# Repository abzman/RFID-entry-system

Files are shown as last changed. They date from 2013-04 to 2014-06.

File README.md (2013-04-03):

RFID-entry-system
=================

RFID entry system for i3 Detroit based on the Open Access Control 3.0, ethernet shield v5, arduino mega 2560, and Static Controls Corporation 1080 displays (RS485)

For an up to date overview please visit http://i3detroit.com/wi/index.php?title=RFID_entry_system

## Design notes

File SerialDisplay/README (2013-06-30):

display test out of date, uses the 2-wire shift register system

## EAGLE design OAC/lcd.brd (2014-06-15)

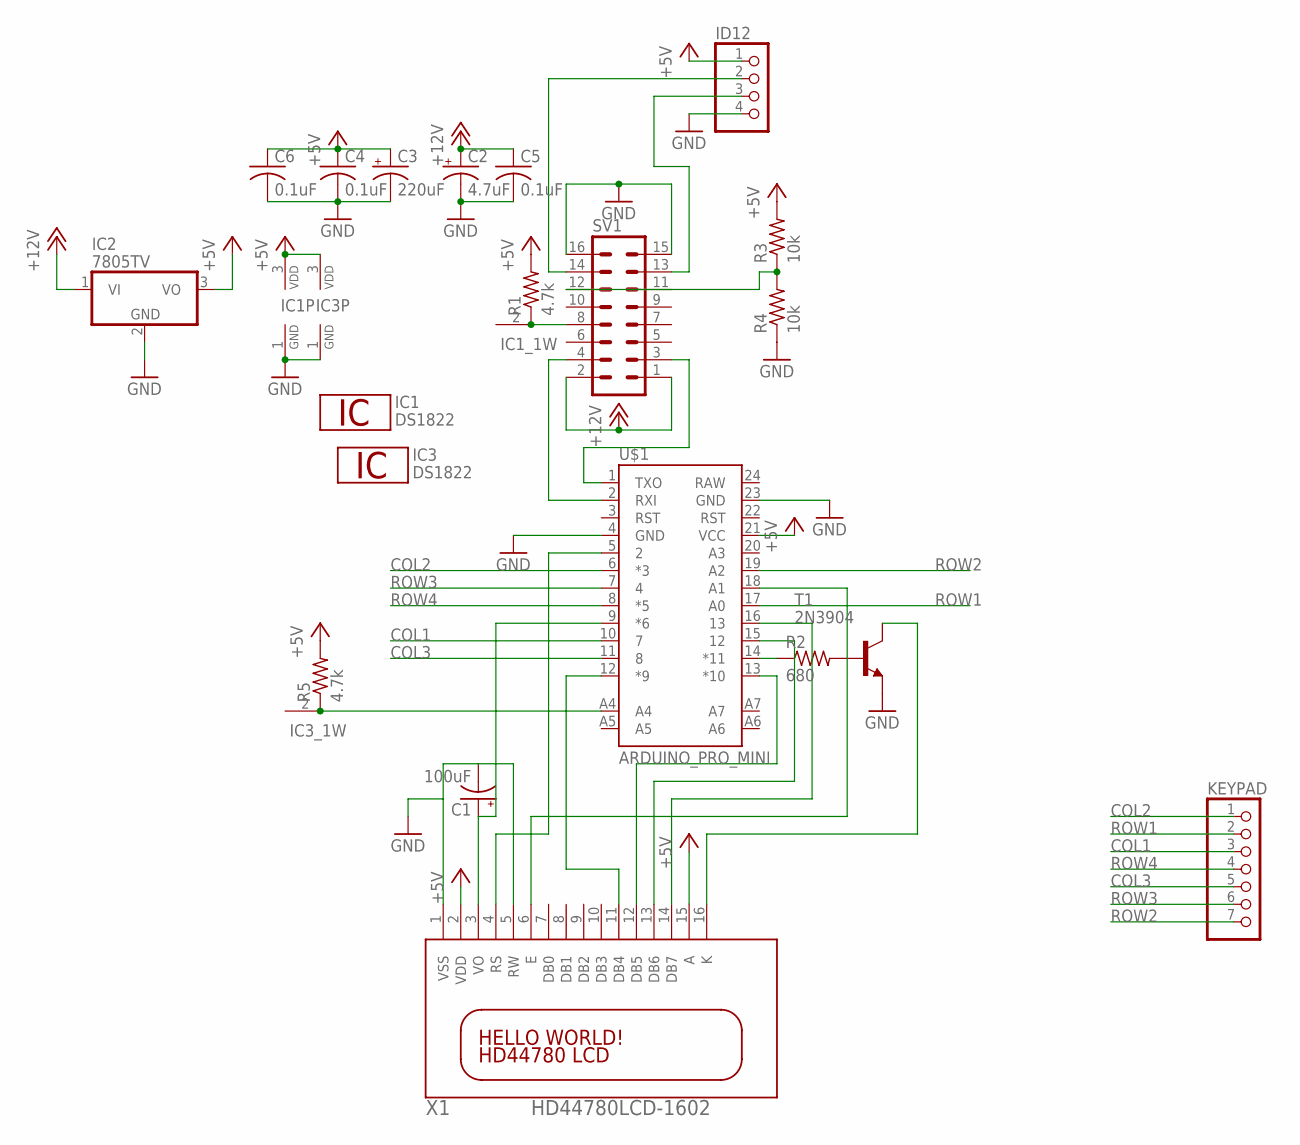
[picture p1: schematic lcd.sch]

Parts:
C1: 100uF; E2,5-7
C2: 4.7uF; E2,5-6
C3: 220uF; E5-8,5
C4, C5, C6: 0.1uF; C025-025X050
IC1, IC3: DS1822; TO92-
IC2: 7805TV; TO220V
ID12: PINHD-1X4; 1X04
KEYPAD: PINHD-1X7; 1X07
R1, R5: 4.7k; 0207/5V
R2: 680; 0207/5V
R3, R4: 10k; 0204V
SV1: ML16
T1: 2N3904; TO92
U$1: ARDUINO_PRO_MINI
X1: HD44780LCD-1602; LCD1602

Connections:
+5V: C3.+, C4.1, C6.1, IC1.3 (VDD), IC2.3 (VO), IC3.3 (VDD), ID12.1, R1.2, R3.2, R5.2, U$1.21 (VCC), X1.2 (VDD), X1.15 (A)
+12V: C2.+, C5.1, IC2.1 (VI), SV1.1, SV1.2
COL1: KEYPAD.3, U$1.10 (7)
COL2: KEYPAD.1, U$1.6 (*3)
COL3: KEYPAD.5, U$1.11 (8)
GND: C1.-, C2.-, C3.-, C4.2, C5.2, C6.2, IC1.1 (GND), IC2.2 (GND), IC3.1 (GND), ID12.4, R4.1, SV1.15, SV1.16, T1.3 (E), U$1.4 (GND), U$1.23 (GND), X1.1 (VSS), X1.5 (RW)
unnamed: IC1.2 (1W), R1.1, SV1.8
unnamed: C1.+, U$1.9 (*6), X1.3 (VO)
unnamed: SV1.4, U$1.2 (RXI)
unnamed: R2.1, U$1.14 (*11)
unnamed: R2.2, T1.2 (B)
unnamed: SV1.3, U$1.1 (TXO)
unnamed: ID12.2, SV1.14
unnamed: ID12.3, SV1.13
unnamed: T1.1 (C), X1.16 (K)
unnamed: U$1.5 (2), X1.4 (RS)
unnamed: U$1.18 (A1), X1.6 (E)
unnamed: U$1.12 (*9), X1.11 (DB4)
unnamed: U$1.13 (*10), X1.12 (DB5)
unnamed: U$1.15 (12), X1.13 (DB6)
unnamed: U$1.16 (13), X1.14 (DB7)
unnamed: R3.1, R4.2, SV1.12
unnamed: IC3.2 (1W), R5.1, U$1.A4
ROW1: KEYPAD.2, U$1.17 (A0)
ROW2: KEYPAD.7, U$1.19 (A2)
ROW3: KEYPAD.6, U$1.7 (4)
ROW4: KEYPAD.4, U$1.8 (*5)

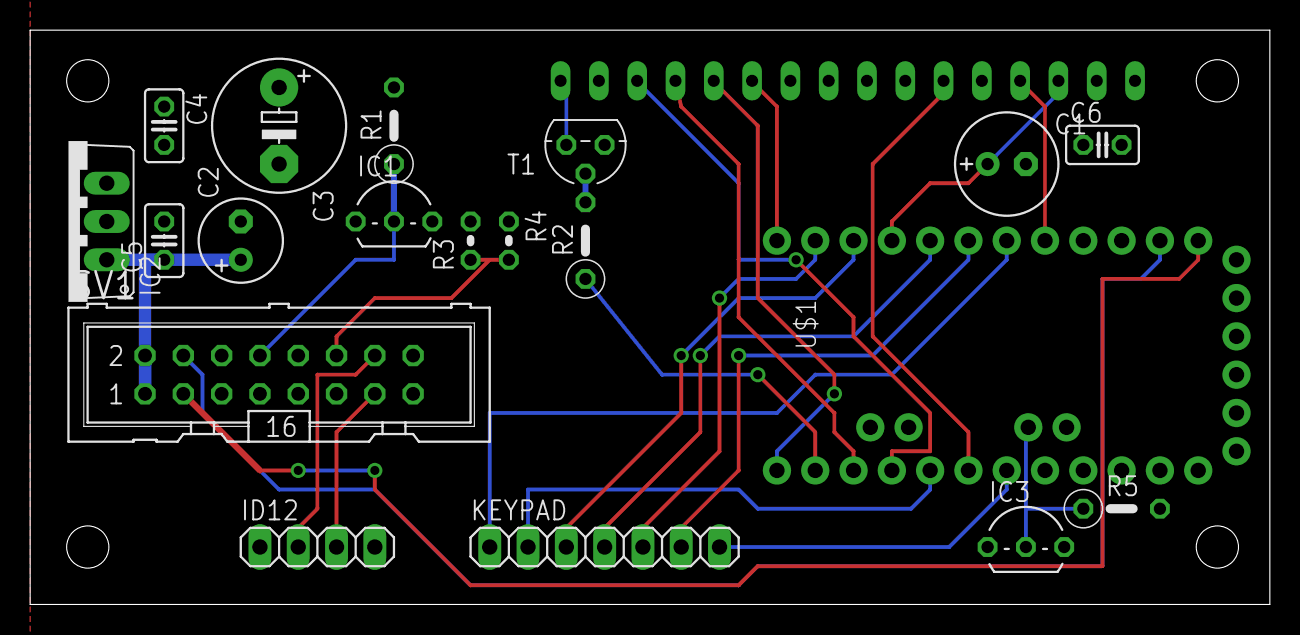
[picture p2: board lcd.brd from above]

Board: 2 copper layers, 82.2 x 38.1 mm, 20 parts (1 on the bottom side), 27 nets.

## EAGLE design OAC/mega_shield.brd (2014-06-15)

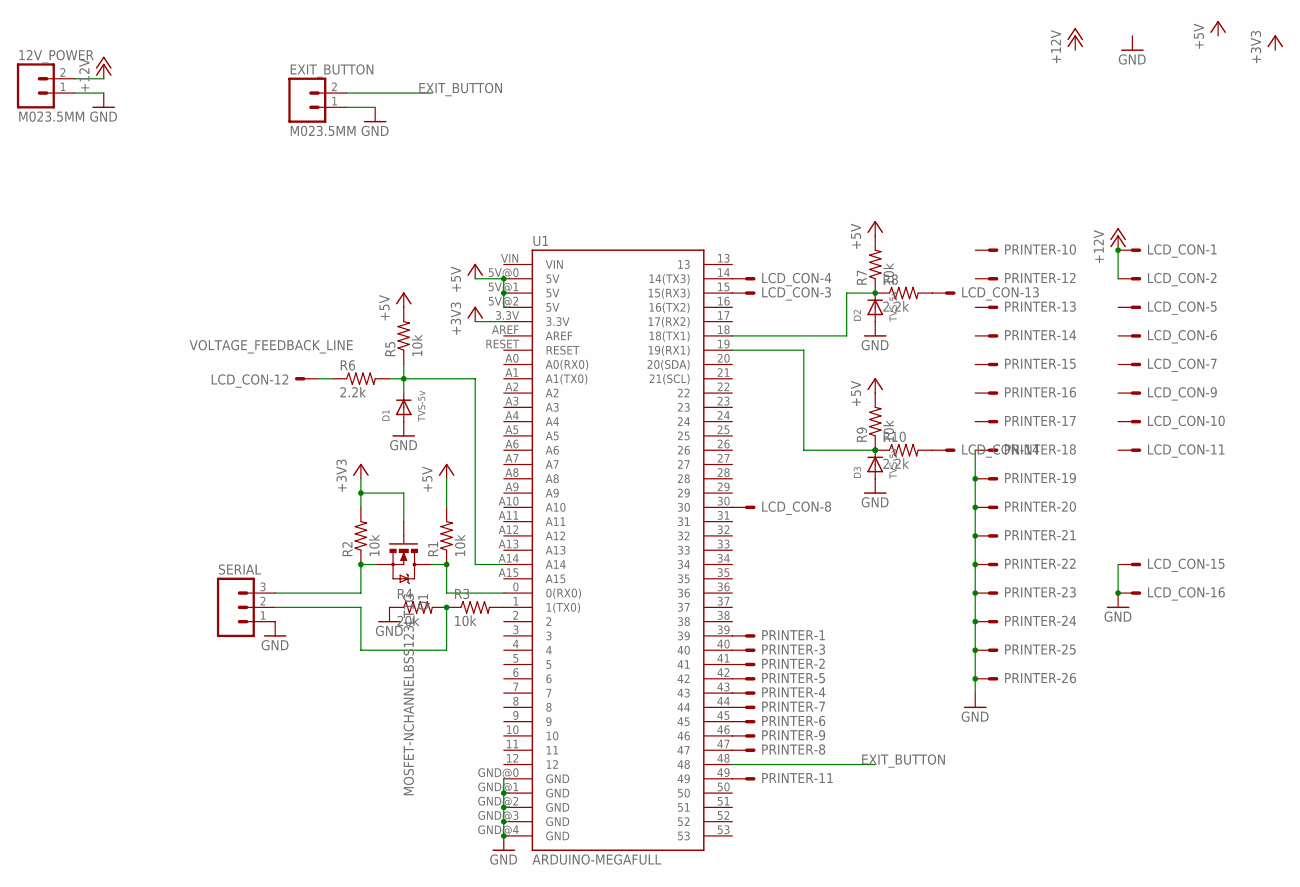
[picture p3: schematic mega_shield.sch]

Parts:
12V_POWER: M023.5MM; SCREWTERMINAL-3.5MM-2
D1, D2, D3: TVS-5v; SOD-123
EXIT_BUTTON: M023.5MM; SCREWTERMINAL-3.5MM-2
LCD_CON: ML16E; ML16
PRINTER: ML26E; ML26
Q1: MOSFET-NCHANNELBSS123LT1G; SOT23
R1, R2, R3, R5, R7, R9: 10k; R0603
R4: 20k; R0603
R6, R8, R10: 2.2k; R0603
SERIAL: M03SCREW; SCREWTERMINAL-3.5MM-3
U1: ARDUINO-MEGAFULL; ARDUINO_MEGA

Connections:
+3V3: Q1.1 (G), R2.2, U1.3.3V
+5V: R1.2, R5.2, R7.2, R9.2, U1.5V@0 (5V), U1.5V@1 (5V), U1.5V@2 (5V)
+12V: 12V_POWER.2, LCD_CON.1, LCD_CON.2
EXIT_BUTTON: EXIT_BUTTON.2, U1.48
GND: 12V_POWER.1, D1.A, D2.A, D3.A, EXIT_BUTTON.1, LCD_CON.15, LCD_CON.16, PRINTER.18, PRINTER.19, PRINTER.20, PRINTER.21, PRINTER.22, PRINTER.23, PRINTER.24, PRINTER.25, PRINTER.26, R4.1, SERIAL.1, U1.GND@0 (GND), U1.GND@1 (GND), U1.GND@2 (GND), U1.GND@3 (GND), U1.GND@4 (GND)
unnamed: LCD_CON.3, U1.15 (15(RX3))
unnamed: LCD_CON.4, U1.14 (14(TX3))
unnamed: PRINTER.1, U1.39
unnamed: PRINTER.11, U1.49
unnamed: PRINTER.2, U1.41
unnamed: PRINTER.3, U1.40
unnamed: PRINTER.4, U1.43
unnamed: PRINTER.5, U1.42
unnamed: PRINTER.6, U1.45
unnamed: PRINTER.7, U1.44
unnamed: PRINTER.8, U1.47
unnamed: PRINTER.9, U1.46
unnamed: LCD_CON.8, U1.30
unnamed: R3.2, U1.1 (1(TX0))
unnamed: R3.1, R4.2, SERIAL.2
unnamed: D1.C, R5.1, R6.2, U1.A14
unnamed: Q1.2 (S), R2.1, SERIAL.3
unnamed: Q1.3 (D), R1.1, U1.0 (0(RX0))
unnamed: D2.C, R7.1, R8.1, U1.18 (18(TX1))
unnamed: D3.C, R9.1, R10.1, U1.19 (19(RX1))
unnamed: LCD_CON.13, R8.2
unnamed: LCD_CON.14, R10.2
VOLTAGE_FEEDBACK_LINE: LCD_CON.12, R6.1

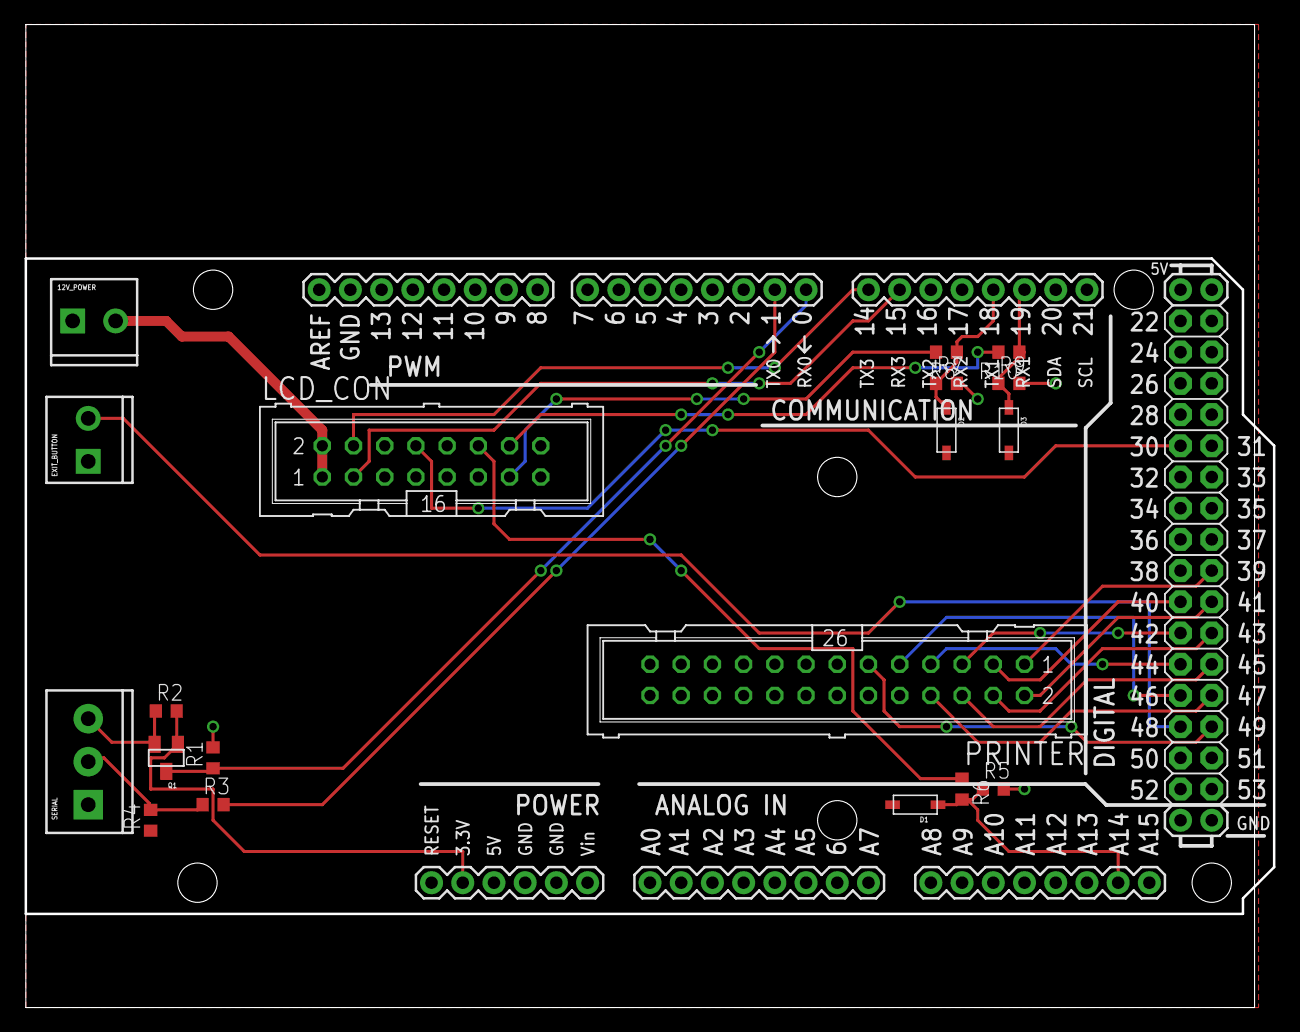
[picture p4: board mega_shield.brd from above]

Board: 2 copper layers, 101.6 x 80.0 mm, 20 parts (0 on the bottom side), 28 nets.

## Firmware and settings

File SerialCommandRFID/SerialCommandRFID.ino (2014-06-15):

// RFID project
// i3 Detroit
// Evan Allen
// January 2014

#define PRIV_ACCESS 0   //allowed to enter space
#define PRIV_ADDUSER 1  //allowed to add or remove users
#define PRIV_DOORBELL 2 //allowed to set doorbell mode
#define PRIV_DOORHOLD 3 //allowed to set door hold mode

#include <MD5.h>
#include <Arduino.h>
#include <String.h>


//library to allow it to take commands from serial
#include <SerialCommand2560.h>
SerialCommand2560 SCmd;   // The demo SerialCommand object


// Interface to DS1822 chip, record data to EEPROM
#include <OneWire.h>
OneWire ds(30);  // define the pin the interface is on */
float current_temperature;

//I2C stuff
#include <Wire.h>         // Needed for I2C Connection to the DS1307 date/time chip
#include <DS1307.h>       // DS1307 RTC Clock/Date/Time chip library
#include <E24C1024.h>     // Needed for the onboard EEPROM
uint8_t second, minute, hour, dayOfWeek, dayOfMonth, month, year;     // Global RTC clock variables. Can be set using DS1307.getDate function.
DS1307 ds1307;        // RTC Instance


//RFID reader stuff
#include <WIEGAND26.h>    // Wiegand 26 reader format library
byte reader1Pins[]={
  19,18};          // Reader 1 connected to pins 19,18
byte reader2Pins[]={
  2,3};          // Reader2 connected to pins 2,3
long reader1 = 0;
int  reader1Count = 0;
long reader2 = 0;
int  reader2Count = 0;
const byte reader2buzz = 6; //pin for the buzzer on Reader2
const byte reader2led = 4; //pin for led1 on Reader2
const byte reader2led2 = 5; //pin for led2 on Reader2
const byte reader1buzz = 7; //pin for the buzzer on Reader1
const byte reader1led = 8; //pin for led1 on Reader1
const byte reader1led2 = 17; //pin for led2 on Reader1
WIEGAND26 wiegand26;


//Get the interrupt number of a given digital pin on an Arduino MEGA.
const byte pinToInterrupt[22] = {
  -1,-1,0,1,-1,-1,-1,-1,-1,-1,-1,-1,-1,-1,-1,-1,-1,-1,5,4,3,2};


//pin-mappings
const int relaysToPins[8] = {
  31,32,33,34,35,36,37,38};
const int analogToPins[16] = {
  54,55,56,57,58,59,60,61,62,63,64,65,66,67,68,69};


//exit button stuff
const int exit_button = 48; //digital pin the exit button is attached to
const int exit_relay = 0; //relay the door solenoid is on
const unsigned long exit_time = 3000; //time to keep the door open in thousandths of a second
boolean exiting = 0; //whether or not the door should be open (and timer running)
unsigned long exit_start_time = 0; //used for count down timer


//RFID timer stuff
const unsigned long RFID_time = 30000; //timeout for the RFID scan in thousandths of a second
unsigned long RFID_start_time = 0; //used for the count down timer


//dot matrix printer stuff
const int dataPins[] = {
  41,40,43,42,45,44,47,46};
const int strobePin = 39;//active low
const int busyPin = 49;//active low


//LCD stuff
int back_val = 255;
int cont_val = 90;
String transmit = "";
String printname = "";

//EEPROM stuff
//if I have time I should figure out why it errors out reading over 512 entries (should get 2048)
int entry_size = 64;
byte hash[32];
//store card id (currently a long, might not need to be)
char name[31];
byte priv;
byte command[64]; //add time zone


//doorbell mode stuff
boolean doorbell = 0; //in doorbell mode?
boolean can_doorbell = 0; //can a given user enter doorbell mode?
unsigned long doorbell_start = 0; //used for count down timer
unsigned long doorbell_dur = (1000*60*60*6); //timeout for doorbell in hours (default 6)


//toggle stuff
//unsigned long max_toggle = 15000; //maximum amount of time a toggle can seize up the processor with a delay loop
unsigned long toggle_dur[8] = {
  0,0,0,0,0,0,0,0}; //time in thousandths of a second
unsigned long toggle_start[8] = {
  0,0,0,0,0,0,0,0}; //start time
boolean toggled[8] = {
  0,0,0,0,0,0,0,0}; //active or not


//door hold mode stuff
boolean doorhold = 0; //in door hold mode?
boolean can_doorhold = 0; //can a given user enter door hold mode?
unsigned long doorhold_start = 0; //used for count down timer
unsigned long doorhold_dur = (1000*60*10); //timeout for door hold in minutes


//battery stuff
float voltage_threshold = 13.6; //threshold to throw an error at
unsigned long battery_start = 0; //used for count down timer
unsigned long battery_dur = (1000*60*15); //time between battery checks (fifteen minutes default)

long tag = 0; //stores tag
boolean tag_read = 0; //in pin reading mode
byte pin[8] = {
  15,15,15,15,15,15,15,15}; //untypeable character, unlike 0
byte digit = 0; //index for pin[]
boolean new_tag_entry = 0; //in new tag entry mode?
boolean can_add = 0; //if a user is permitted to add other users
int num_users = 500; //number of users the EEPROM can take before it errors out (should debug this)
unsigned long current_time = millis();

void setup()
{  

  Wire.begin();   // start Wire library as I2C-Bus Master
  Serial.begin(115200); 
  RFID_init();
  IO_init();
  printer_init();
  LCD_init();
  // Setup callbacks for SerialCommand commands 
  SCmd.addCommand("ON",SCmd_relay_on);       // Turns relay on
  //format: ON;<relay number(not pin number)>
  SCmd.addCommand("OFF",SCmd_relay_off);        // Turns relay off
  //format: OFF;<relay number(not pin number)> 
  SCmd.addCommand("TOGGLE",SCmd_toggle);  // Toggles relay with duration
  //format: TOGGLE;<relay number(not pin number)>;<time to be on for in a 'delay(arg)' format>
  SCmd.addCommand("RTC",SCmd_rtc);  // uses RTC
  //format: RTC;<0=write, 1=read>;<second, 0-59 (write only)>;<minute,0-59 (write only)>;<hour, 1-23 (write only)>;<dayOfWeek, 1-7 (write only)>;<dayOfMonth, 1-28/29/30/31 (write only)>;<month, 1-12 (write only)>;<year, 0-99 (write only)>
  SCmd.addCommand("DISP",SCmd_display);  // uses display
  //format: DISP;<0=line 1, 1=line 2 (or no argument to clear the display)>;<string (or no argument to clear the line)>
  SCmd.addCommand("PRINT",SCmd_print);  // uses printer
  //format: PRINT;<string>
  SCmd.addCommand("CONTRAST",SCmd_contrast);  // sets contrast
  //format: CONTRAST;<analog value, 0-255 or nothing for default>
  SCmd.addCommand("BACKLIGHT",SCmd_backlight);  // sets backlight
  //format: BACKLIGHT;<analog value, 0-255 or nothing for default>
  SCmd.addCommand("BAT",check_battery);  // reads battery voltage
  //format: BAT
  SCmd.addCommand("TEMP",check_temp);  // reads temperature
  //format: TEMP
  SCmd.addCommand("BEEP",SCmd_beep);  // beeps reader<reader number> for <duration> in delay(arg) format
  //format: BEEP;<reader number>,<duration>
  SCmd.addCommand("READ_CMD",SCmd_read_CMD);  // dumps the command area of the EEPROM
  //format: READ_CMD
  SCmd.addCommand("DUMP_USR",SCmd_dump_users);  // dumps all users up to index
  //format: DUMP_USR
  SCmd.addCommand("ADD_USR",SCmd_add_user);  // adds a user at a given index
  //format: ADD_USR;<index>;<name>;<priv byte>;<hash>
  SCmd.addCommand("READ_USR",SCmd_read_user);  // reads the user at <index>
  //format: READ_USR;<index>
  SCmd.addCommand("RMV_USR",SCmd_remove_user);  // removes the user at <index>
  //format: RMV_USR;<index>
  SCmd.addCommand("RMV_USRN",SCmd_remove_user_name);  // removes the user with <name>
  //format: RMV_USRN;<name>
  SCmd.addCommand("RMV_USRH",SCmd_remove_user_hash);  // removes the user with <hash>
  //format: RMV_USRH;<hash>
  SCmd.addDefaultHandler(unrecognized);  // Handler for command that isn't matched  (says "What?") 

  logging(logDate());
  logging(" - ");
  loggingln("Rebooted"); 
  check_battery(); //log battery at boot
  check_temp(); //log temp at boot
  LCD_default();
  //Serial.println("done");
  //populate_blank_users();
  //write_EE(0,"Evan", 15, "9a7eaa8c16bd8073d32991d7ddc8a480");
  //write_EE(1,"Charlie", 4, "dacbac186709549ff6f16b6a7df0dd1c");
  //write_EE(2,"Mike", 7, "22df7bee944f0b02bc0b9ce8b826e862");
  //write_EE(3,"Whoever", 1, "d2e8102a9b4d8bcd20d38cb1fa2b0ddc");
  //write_EE(4,"Lego", 3, "3bf21d79f6516b061a8326fda21d6af3");
  //blank_EE_cmd();
  //command[0] = 5;
  //write_EE_cmd();
  //dump_all_EE();
  //EE_dump_users();
}


void loop()
{
  //Serial.println(freeRam());
  // Serial.println(reader2Count);
  SCmd.readSerial();     //process serial commands
  current_time = millis();  //saves from calling that function a bunch in the main loop
  if (!digitalRead(exit_button)) //exit button pressed
  {
    //Serial.println("exiting");
    exit();
  }
  //Serial.println("past exiting");

  if (current_time - battery_start > battery_dur) //battery timer loop
  {
    //Serial.println("checking battery");
    check_battery();
  }
  //Serial.println("past checking battery");

  for(int i=0;i<8;i++) //toggle timer loops
  {
    //Serial.println("checking toggled");
    if (toggled[i])
    {
      //Serial.println(millis() - toggle_start[i]);
      if (current_time - toggle_start[i] > toggle_dur[i])
      {
        toggled[i] = 0;
        digitalWrite(relaysToPins[i], LOW);
      }
    }
  }

  if(doorbell) //doorbell timer loop
  {
    if (current_time - doorbell_start > doorbell_dur)
    {
      doorbell = 0;
    }
  }
  //Serial.println("past doorbell");
  if(doorhold) //door hold timer loop
  {
    if (current_time - doorhold_start > doorhold_dur)
    {
      doorhold = 0;
    }
  }
  //Serial.println("past doorhold");
  if (tag_read)
  {
    //Serial.println("tag read");
    if (current_time - RFID_start_time > RFID_time) //RFID time out loop
    {
      //Serial.println("tag timeout");
      LCD_clear();
      LCD_displn("RFID timeout",0);
      RFID_error_out();
    }

    char keypad_button = keypad_matrix();
    if (keypad_button != ' ') //reading a button in tag read mode
    {
      //Serial.println("button pressed");
      if(keypad_button == '*') //escape
      {
        //Serial.println("backspace");
        backspace_pin();
      }
      else if(keypad_button == '#')  //enter
      {
        //Serial.println("enter");
        if (new_tag_entry ==1)
        {
          //Serial.println("new tag");
          new_user_entry();
        }
        else
        {
          //Serial.println("current tag");
          current_user_entry();
        }
      }
      else //other numbers
      {
        //Serial.println("enter pin");
        enter_pin(keypad_button);
      }
    }
  }
  else
  {
    //Serial.println("no tag read");
    char keypad_button = keypad_matrix();
    if (keypad_button != ' ')  //just reading raw buttons, not in tag reading mode
    {
      //Serial.println("button pressed");
      if(keypad_button == '5' && exiting == 1 && can_add == 1)//button press for adding a user
      {
        can_add = 0;
        can_doorbell = 0;
        can_doorhold = 0;
        enter_new_tag_entry_mode();
      }
      if(keypad_button == '2' && exiting == 1 && can_doorbell == 1)//button press for doorbell mode
      {
        can_add = 0;
        can_doorbell = 0;
        can_doorhold = 0;
        if(!doorbell)
        {
          enter_doorbell_mode();
        }
        else
        {
          exit_doorbell_mode();
        }
      }
      if(keypad_button == '3' && exiting == 1 && can_doorhold == 1)//button press for door hold mode
      {
        can_add = 0;
        can_doorbell = 0;
        can_doorhold = 0;
        if(!doorhold)
        {
          enter_doorhold_mode();
        }
        else
        {
          exit_doorhold_mode();
        }
      }
      if(keypad_button == '#' && doorbell == 1)//button press in doorbell mode, combine with below
      {
        exit();
        beep_reader(2,300);
      }
      if(keypad_button == '#' && doorhold == 1)//button press in door hold mode, combine with above
      {
        exit();
        beep_reader(2,300);
      }
      //Serial.print("Button = ");
      //Serial.println(keypad_button);
    }
  }

  if(digit == (sizeof(pin)/sizeof(pin[0]))+1) //too big pin
  {
    logging(logDate());
    logging(" - ");
    loggingln("pin overflow");
    LCD_clear();
    LCD_displn("Error:",0);
    LCD_displn("pin too big",1);
    RFID_error_out();
  }

  if (exiting) 
  {
    if (current_time - exit_start_time > exit_time) //exit time out loop
    {
      exit_timeout();
    }
  }
  if (reader2Count >= 26) //read tag for new input, start tag reading mode (accepting buttons as pin)
  {
    reset_tag_reading(2);
  }
  if (reader1Count >= 26) //read tag for new input, start tag reading mode (accepting buttons as pin)
  {
    reset_tag_reading(1);
  }
  //delay(100);
  //account for reader#Count == 4
}

int freeRam(void)
{
  extern int  __bss_end; 
  extern int  *__brkval; 
  int free_memory; 
  if((int)__brkval == 0) {
    free_memory = ((int)&free_memory) - ((int)&__bss_end); 
  }
  else {
    free_memory = ((int)&free_memory) - ((int)__brkval); 
  }
  return free_memory; 
} 

void LCD_init()
{
  Serial3.begin(115200);
  LCD_clear();
    
    transmit = "CONTRAST;";
    transmit += cont_val;
    Serial3.println(transmit);
      
    transmit = "BACKLIGHT;";
    transmit += back_val;
    Serial3.println(transmit);
}


void IO_init()
{
  for (int i=0;i<sizeof(relaysToPins)/sizeof(relaysToPins[0]);i++)
  {
    pinMode(relaysToPins[i], OUTPUT);
  }
  for (int i=0;i<sizeof(analogToPins)/sizeof(analogToPins[0]);i++)
  {
    pinMode(analogToPins[i], INPUT);//not needed?
  }
  pinMode(exit_button,INPUT_PULLUP);//pullup not needed?
}


void printer_init()
{
  for (int i = 0; i < sizeof(dataPins) / sizeof(dataPins[0]); ++i)
    pinMode(dataPins[i], OUTPUT);
  pinMode(strobePin, OUTPUT);
  pinMode(busyPin, INPUT);     
  digitalWrite(strobePin, HIGH);
}


void RFID_init()
{
  pinMode(reader2buzz, OUTPUT);
  pinMode(reader2led, OUTPUT);
  pinMode(reader2led2, OUTPUT);
  digitalWrite(reader2led, 1); //active low
  digitalWrite(reader2led2, 1); //active low
  digitalWrite(reader2buzz, 1); //active low
  attachInterrupt(pinToInterrupt[reader2Pins[1]], callReader2One,  CHANGE);
  attachInterrupt(pinToInterrupt[reader2Pins[0]], callReader2Zero, CHANGE);
  wiegand26.initReaderTwo();


  pinMode(reader1buzz, OUTPUT);
  pinMode(reader1led, OUTPUT);
  pinMode(reader1led2, OUTPUT);
  digitalWrite(reader1led, 1); //active low
  digitalWrite(reader1led2, 1); //active low
  digitalWrite(reader1buzz, 1); //active low
  attachInterrupt(pinToInterrupt[reader1Pins[1]], callReader1One,  CHANGE);
  attachInterrupt(pinToInterrupt[reader1Pins[0]], callReader1Zero, CHANGE);
  wiegand26.initReaderOne();
}


// logs temperature
void check_temp()
{
  char temp[8];
  current_temperature = getTemp();//stored for calculation of contrast value later
  ftoa(temp,current_temperature,2);
  //dtostrf(voltage,8,2,volt); should work?
  printname = "Temperature outside: ";
  printname += temp;

  logging(logDate());
  logging(" - ");
  loggingln(printname);
}


float getTemp()
{
  byte data[9];
  byte addr[8];
  int temp;

  while ( !ds.search(addr)) 
  {
    //Serial.print("No more addresses.\n");
    ds.reset_search();
  }
  ds.reset();
  ds.select(addr);
  ds.write(0x44,1);
  delay(600);
  byte present = ds.reset();
  ds.select(addr);    
  ds.write(0xBE);
  for (byte i = 0; i < 9; i++) 
  {
    data[i] = ds.read();
  }
  boolean negative = (data[1] & 1<<5);
  data[1] <<=4;
  data[1] >>=4;
  temp = data[1];
  temp <<= 8;             /* shift left eight bits */
  temp += data[0];        /* add second byte of temperature */
  float tempFloat = (float)temp/16.0;
  if(negative)
  {
    tempFloat = -tempFloat;
  }
  return tempFloat;
}


char keypad_matrix()
{
  //Serial.println("keypad_matrix");
  if(Serial3.available())
  {
    char result = Serial3.read();//Read key press
    return result;
  }
  else
  {
    return ' ';//equivalent to -1, a null result
  }
  //delay(10);
}


void LCD_default()
{
  LCD_clear();
  if(doorbell)
  {
    LCD_displn("Welcome: press  ",0);
    LCD_displn("\"#\" to enter    ",1);
  }
  else if(doorhold)
  {
    LCD_displn("Door held: press",0);
    LCD_displn("\"#\" to enter    ",1);
  }
  else
  {
    LCD_displn("i3 Detroit      ",0);
    LCD_displn("Hackerspace     ",1);
  }
}

void exit_timeout()
{
  logging(logDate());
  logging(" - ");
  loggingln("exit relay closed");
  LCD_default();
  RFID_reset();
  exiting = 0; //no longer in exiting mode
  //exit_start_time = 0; //not needed
  digitalWrite(relaysToPins[exit_relay], LOW); //close door
}

// reads battery voltage
void check_battery()
{
  battery_start = millis();
  float voltage = ((float)(analogRead(A15)*20)/1024.0);
  if(voltage<voltage_threshold)
  {
    battery_dur = (1000*60*5); //set to 2 mins
    logging(logDate());
    logging(" - ");
    loggingln("battery voltage dropped below threshold");
  }
  else
  {
    battery_dur = (1000*60*15); //set to 1 hour
  }

  char volt[8];
  ftoa(volt,voltage,2);
  //dtostrf(voltage,8,2,volt); should work?
  printname = "Battery voltage: ";
  printname += volt;

  logging(logDate());
  logging(" - ");
  loggingln(printname);
}


char *ftoa(char *a, double f, int precision)
{
  long p[] = {
    0,10,100,1000,10000,100000,1000000,10000000,100000000  };

  char *ret = a;
  long heiltal = (long)f;
  itoa(heiltal, a, 10);
  while (*a != '\0') a++;
  *a++ = '.';
  long decimal = abs((long)((f - heiltal) * p[precision]));
  itoa(decimal, a, 10);
  return ret;
}


void exit_doorbell_mode()
{
  logging(logDate());
  logging(" - ");
  loggingln("exit doorbell mode");
  LCD_clear();
  LCD_displn("doorbell mode",0);
  LCD_displn("deactivated",1);
  doorbell = 0;
  //doorbell_start = 0;
  //can_doorbell = 0;
}


void enter_doorbell_mode()
{
  logging(logDate());
  logging(" - ");
  loggingln("enter doorbell mode");
  LCD_clear();
  LCD_displn("doorbell mode",0);
  LCD_displn("activated",1);
  doorbell =1;
  doorbell_start = current_time;
  //can_doorbell = 0;
}


void exit_doorhold_mode()
{
  logging(logDate());
  logging(" - ");
  loggingln("exit door hold mode");
  LCD_clear();
  LCD_displn("door hold mode",0);
  LCD_displn("deactivated",1);
  doorhold = 0;
  //doorhold_start = 0;
  //can_doorhold = 0;
}


void enter_doorhold_mode()
{
  logging(logDate());
  logging(" - ");
  loggingln("enter door hold mode");
  LCD_clear();
  LCD_displn("door hold mode",0);
  LCD_displn("activated",1);
  doorhold =1;
  doorhold_start = current_time;
  //can_doorhold = 0;
}


void enter_new_tag_entry_mode()
{
  exit_timeout();
  logging(logDate());
  logging(" - ");
  loggingln("new member attempt");
  LCD_clear();
  LCD_displn("New member:",0);
  LCD_displn("swipe new tag",1);
  new_tag_entry = 1;
}


void exit()
{
  logging(logDate());
  logging(" - ");
  loggingln("exit relay open");
  exiting = 1;
  exit_start_time = current_time;
  digitalWrite(relaysToPins[exit_relay], HIGH);
}


void new_user_entry()
{
  //Serial.print("Tag = ");
  //Serial.println(tag,DEC);
  //Serial.print("Pin = ");
  //for(int i=0;i<digit;i++)
  //{
  //	Serial.print(pin[i]);      
  //}
  if (digit<4) //too short of a pin
  {
    clear_pin();
    int d = 300;
    LCD_clear();
    LCD_displn("pin too short",0);
    beep_repeat(2,200,2);
    reader2 = tag;//hack
    reset_tag_reading(2);//hack
    RFID_start_time = millis();
  }
  else
  {
    String toHash = "";
    toHash += tag;
    //put in raw tag to eeprom
    for(int i=0;i<(sizeof(pin)/sizeof(pin[0]));i++)
    {
      toHash += pin[i];   
    }
    clear_pin();
    char hashed[32];
    toHash.toCharArray(hashed,32); 
    char *md5str = MD5::make_digest(MD5::make_hash(hashed), 16);
    for (int i=0;i<num_users;i++)
    {
      if(!user_present(i))
      {
        String name = "New Member ";
        name += logDate();
        priv= 1;
        //put in raw tag to eeprom
        write_EE(i, name, priv, md5str);
        break;
      }
    }
    //Serial.println(md5str);
    logging(logDate());
    logging(" - ");
    logging("new user ");
    logging(md5str);
    loggingln(" added");
    LCD_clear();
    LCD_displn("Welcome",0);
    LCD_displn("New member",1);

    for(int i=0;i<(sizeof(hashed)/sizeof(hashed[0]));i++) //also should not be needed
    {
      hashed[i] = 0;   
    }
    new_tag_entry = 0;
    toHash = ""; //not needed?
    RFID_reset();
    exit();
  }
}

void current_user_entry()
{
  //possibly add a time based lack of pin requirement, for example 
  //store a list of user IDs that have no pin entry allowed, reset 
  //it at midnight (or noon) and check the card id against all of those before hashing, etc...
  
  //Serial.print("Tag = ");
  //Serial.println(tag,DEC);
  //Serial.print("Pin = ");
  //for(int i=0;i<digit;i++)
  //{
  //	Serial.print(pin[i]);      
  //}
  String toHash;
  toHash += tag;
  for(int i=0;i<(sizeof(pin)/sizeof(pin[0]));i++)
  {
    toHash += pin[i];   
  }
  clear_pin();
  char hashed[32];
  toHash.toCharArray(hashed,32); 
  char *md5str = MD5::make_digest(MD5::make_hash(hashed), 16);
  if(authenticate(md5str) == 1)
  {
    logging(logDate());
    logging(" - ");
    printname = "";
    for (int j = 0; j < (sizeof(name)/sizeof(name[0])); j++)
    {
      if(name[j] != 0)
      {
        printname += name[j];
        //Serial.println(name[j],HEX);
      }
    }
    logging(printname);
    loggingln(" carded in");
    LCD_clear();
    LCD_displn("Welcome Member:",0);
    LCD_displn(printname,1);
    exit();
  }
  else
  {
    logging(logDate());
    logging(" - ");
    //logging(md5str);//
    //logging(" - ");//
    loggingln("card entry failed");
    LCD_clear();
    LCD_displn("Invalid entry",0);
    RFID_error_out();
  }
  //Serial.println(md5str);
  //Serial.println();
  //Serial.println(test);
  for(int i=0;i<(sizeof(hashed)/sizeof(hashed[0]));i++)//should not be needed
  {
    hashed[i] = 0;   
  }
  toHash = ""; //also not needed?
  RFID_reset();
}



void backspace_pin()
{
  pin[digit] = 15;
  //Serial.println("backspace");
  LCD_displn("                ",1);
  LCD_displn("Pin:",1);
  if(digit >0)
  {
    digit--;
    pin[digit] = 15;
  }
  for (int i = 0;i<digit;i++)//repopulates asterisks
  {
    LCD_disp("*");
  }
  //for(int i=0;i<(sizeof(pin)/sizeof(pin[0]));i++)
  //{
  //	Serial.print(pin[i]);      
  //}
}
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

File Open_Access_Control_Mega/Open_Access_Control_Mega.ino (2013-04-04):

/*
 * Open Source RFID Access Controller
 * Mega version for v3.0 HARDWARE
 * 
 * 5/4/2012 v1.01
 * based on Open Access v1.33
 * Last build test with Arduino v1.0
 * Arclight - arclight@23.org
 * Danozano - danozano@gmail.com
 *
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
 * Open Source and Commercial versions of the hardware available
 * For latest downloads, including Eagle CAD files for the hardware, check out
 * http://WWW.ACCXPRODUCTS.COM  
 *
 * Latest update moves strings to PROGMEM to free up memory and adds a 
 * console password feature.
 * 
 *
 * This program interfaces the Arduino to RFID, PIN pad and all
 * other input devices using the Wiegand-26 Communications
 * Protocol. It is recommended that the keypad inputs be
 * opto-isolated in case a malicious user shorts out the 
 * input device.
 * Outputs go to a Darlington relay driver array for door hardware/etc control.
 * Analog inputs are used for alarm sensor monitoring.  These should be
 * isolated as well, since many sensors use +12V. Note that resistors of
 * different values can be used on each zone to detect shorting of the sensor
 * or wiring.
 *
 * Version 3.0 of the Mega hardware implements these features and uses the following pin 
 * assignments on a standard Arduino Duemilanova or Uno:
 *
 * Relay outpus on digital pins 31..38
 * DS1307 Real Time Clock (I2C):20 (SDA), 21 (SCL)
 * Analog pins (for alarm):A0..A14
 * Battery Level pin: A15
 * Reader 1: pins 2,3
 * Reader 2: pins 19,18
 * Ethernet/SPI: pins 50,51,52,53 (Not connected to the board, reserved)
 *
 * Quickstart tips: 
 * Set the console password(PRIVPASSWORD) value to a numeric DEC or HEX value.
 * Define the static user list by swiping a tag and copying the value received into the #define values shown below 
 * Compile and upload the code, then log in via serial console at 57600,8,N,1
 *
 */

#include <Wire.h>         // Needed for I2C Connection to the DS1307 date/time chip
#include <EEPROM.h>       // Needed for saving to non-voilatile memory on the Arduino.
#include <avr/pgmspace.h> // Allows data to be stored in FLASH instead of RAM

/*
#include <Ethernet.h>   // Ethernet stuff, comment out if not used.
#include <SPI.h>          
#include <Server.h>
#include <Client.h>
*/

#include <DS1307.h>       // DS1307 RTC Clock/Date/Time chip library
#include <WIEGAND26.h>    // Wiegand 26 reader format libary



/* Static user List - Implemented as an array for testing and access override 
 */                               

#define DEBUG 2                         // Set to 2 for display of raw tag numbers in log files, 1 for only denied, 0 for never.               

#define gonzo   0x1234                  // Name and badge number in HEX. We are not using checksums or site ID, just the whole
#define snake   0x1234                  // output string from the reader.
#define satan   0x1234
const long  superUserList[] = { gonzo, snake, satan};  // Super user table (cannot be changed by software)

#define PRIVPASSWORD 0x1234             // Console "priveleged mode" password

#define DOORDELAY 5000                  // How long to open door lock once access is granted. (2500 = 2.5s)
#define SENSORTHRESHOLD 100             // Analog sensor change that will trigger an alarm (0..255)

#define EEPROM_ALARM 0                  // EEPROM address to store alarm triggered state between reboots (0..511)
#define EEPROM_ALARMARMED 1             // EEPROM address to store alarm armed state between reboots
#define EEPROM_ALARMZONES 20            // Starting address to store "normal" analog values for alarm zone sensor reads.
#define KEYPADTIMEOUT 5000              // Timeout for pin pad entry. Users on keypads can enter commands after reader swipe.

#define EEPROM_FIRSTUSER 48
#define EEPROM_LASTUSER 2048
#define NUMUSERS  ((EEPROM_LASTUSER - EEPROM_FIRSTUSER)/5)  //Define number of internal users (200 for UNO/Duemillanova, 400 for Mega)


#define DOORPIN1 relayPins[0]           // Define the pin for electrified door 1 hardware
#define DOORPIN2 relayPins[1]           // Define the pin for electrified door 2 hardware
#define ALARMSTROBEPIN relayPins[2]     // Define the "non alarm: output pin. Can go to a strobe, small chime, etc
#define ALARMSIRENPIN  relayPins[3]     // Define the alarm siren pin. This should be a LOUD siren for alarm purposes.

uint8_t reader1Pins[]={2,3};               // Reader 1 connected to pins 2,3
uint8_t reader2Pins[]= {19,18};            // Reader2 connected to pins 19,18


const uint8_t analogsensorPins[] = {0,1,2,3,4,5,6,7,8,9,10,11,12,13,14};    // Alarm Sensors connected to other analog pins
const uint8_t relayPins[]= {31,32,33,34,35,36,37,38};                       // Relay output pins

bool door1Locked=true;                          // Keeps track of whether the doors are supposed to be locked right now
bool door2Locked=true;

unsigned long door1locktimer=0;                 // Keep track of when door is supposed to be relocked
unsigned long door2locktimer=0;                 // after access granted.

boolean doorChime=false;                        // Keep track of when door chime last activated
boolean doorClosed=false;                       // Keep track of when door last closed for exit delay

unsigned long alarmDelay=0;                     // Keep track of alarm delay. Used for "delayed activation" or level 2 alarm.
unsigned long alarmSirenTimer=0;                // Keep track of how long alarm has gone off


unsigned long consolefailTimer=0;               // Console password timer for failed logins
uint8_t consoleFail=0;
#define numSuperUsers (sizeof(superUserList)/sizeof(long))                  //User access array size (used in later loops/etc)
#define NUMDOORS (sizeof(doorPin)/sizeof(uint8_t))
#define numAlarmPins (sizeof(analogsensorPins)/sizeof(uint8_t))

//Other global variables
uint8_t second, minute, hour, dayOfWeek, dayOfMonth, month, year;     // Global RTC clock variables. Can be set using DS1307.getDate function.

uint8_t alarmActivated = EEPROM.read(EEPROM_ALARM);                   // Read the last alarm state as saved in eeprom.
uint8_t alarmArmed = EEPROM.read(EEPROM_ALARMARMED);                  // Alarm level variable (0..5, 0==OFF) 

boolean sensor[4]={false};                                         // Keep track of tripped sensors, do not log again until reset.
unsigned long sensorDelay[2]={0};                                  // Same as above, but sets a timer for 2 of them. Useful for logging
                                                                   // motion detector hits for "occupancy check" functions.

// Enable 2 door access readers.
volatile long reader1 = 0;
volatile int  reader1Count = 0;
volatile long reader2 = 0;
volatile int  reader2Count = 0;
int userMask1=0;
int userMask2=0;
boolean keypadGranted=0;                                       // Variable that is set for authenticated users to use keypad after login
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

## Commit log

2013-04-06 printer working
2013-06-21 working everything (incliding printer)
2013-06-29 final commit before removing the SCC 1080 code (switching to HD44780)
2013-06-30 changed to 44780 on 3 wire 595 spi and a 4017 keypad matrix
2013-07-12 final configuration, still buggy
    [SerialCommandRFID.ino]
2014-06-15 added uart_lcd
2014-06-15 added board files
    [lcd.brd, lcd.sch, mega_shield.brd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]

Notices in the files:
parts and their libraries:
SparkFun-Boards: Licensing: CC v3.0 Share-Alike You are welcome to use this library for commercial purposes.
